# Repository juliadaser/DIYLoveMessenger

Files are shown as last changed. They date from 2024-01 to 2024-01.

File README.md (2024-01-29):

# DIY Love Messenger
By Julia Daser and Pepi Ng

Demo of Love Messengers working:
<br>
<br>
demo

## About 
Our DIY Love Messengers are the perfect gift for your friends/ partners, especially long-distance ones! When the button of one love messenger is pressed, both of them will light up - no matter HOW FAR AWAY the two messengers are! All files, code and 3D models can be found in this repository.

We also documented this in a [tutorial](https://www.youtube.com/watch?v=Ot5ihNqtx74&feature=youtu.be&ab_channel=WormiCollective)!

We are using the ESP32 microcontrollers for this tutorial. We also created a previous tutorial on [How to send data between many ESP32s from anywhere in the world](https://www.youtube.com/watch?v=Xx5cEIbBvZY&ab_channel=WormiCollective).

### Materials needed for TWO Love Messengers
1. Some translucent filament for the heart. We used [this from Elegoo](https://www.elegoo.com/products/elegoo-pla-filament-1-75mm-3d-printer-filament-1kg-spool-2-2-lbs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) 
2. Some filament of your choice, for the casing.
3. [2 ESP32-WROOM-32 microcontrollers](https://www.getfpv.com/esp32-development-board-w-wifi-bluetooth.html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) ($6.99 per)
4. [2 Adafruit 16mm illuminated push buttons](https://www.adafruit.com/product/1478) ($1.95 per)
5. Some wires
6. [Some heat shrink tubes](https://www.adafruit.com/product/1649) ($4.95 per)
7. [Two RGB LEDs](https://www.adafruit.com/product/159) ($2.00 per) 
8. [2 Micro-USB wires used to power and to transmit data](https://www.bestbuy.com/site/best-buy-essentials-3-usb-a-to-micro-usb-charge-and-sync-cable-black/6456436.p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) ($4.99 per)
9. [8x M2-0.4 x 10 mm Screws](https://www.homedepot.com/p/Prime-Line-M2-0-4-x-10-mm-Grade-A2-70-Metric-Stainless-Steel-Phillips-Drive-Pan-Head-Machine-Screws-10-Pack-9130681/311229806) ($4.69 for a pack of 10)
10. [6x 220ohm Resistors](https://www.adafruit.com/product/2780) ($0.75 for pack of 25)

### Equipment needed
1. 3D printer
2. Pliers
3. Wire Stripper
4. Small Screwdriver
5. Soldering Kit
6. Solder Sucker
7. Heat Gun / Rework station

## Process
The tutorial includes 3D printing, setting up a real-time database (we used [Firebase](https://firebase.google.com/)), uploading some arduino code and assembling everything together! 

Everything is documented in our YouTube Video. Here's the wiring diagram we used: 
<br>
<br>
<br>
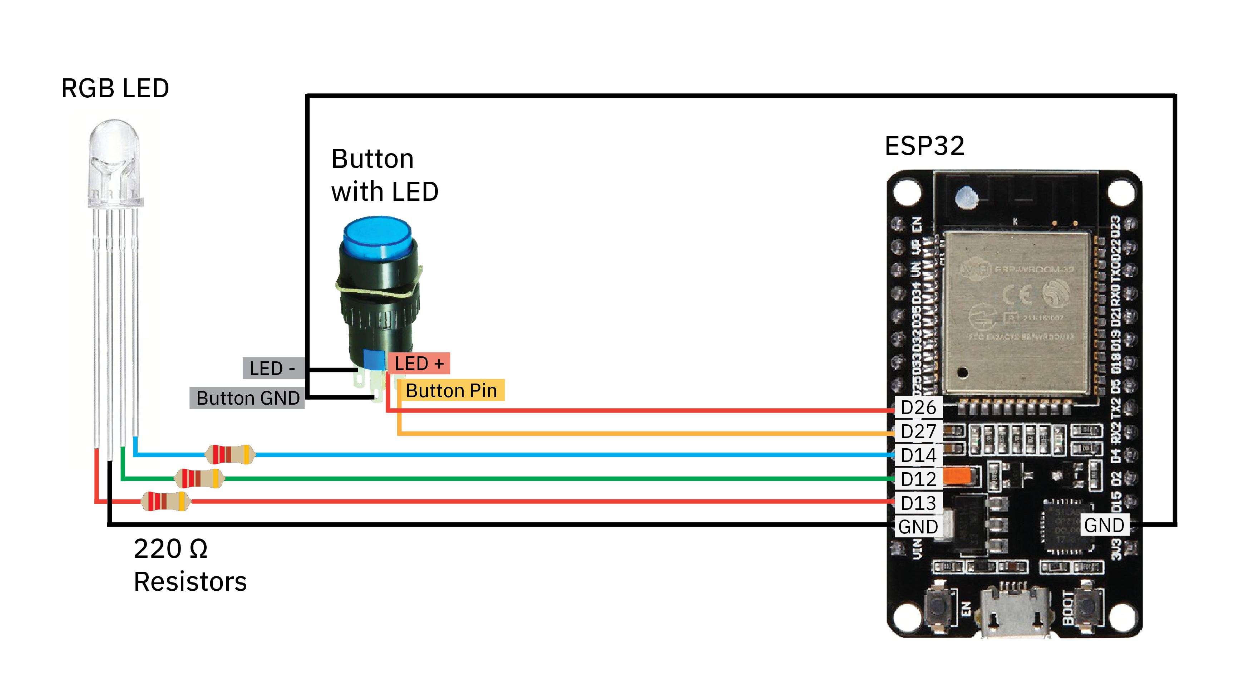
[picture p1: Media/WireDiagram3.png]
wire diagram


## Contact us
We hope you guys had tons of fun building these DIY Love Messengers as much as we did!  If you have any questions/ feedback, do reach us at yiqing.ng@gmail.com.

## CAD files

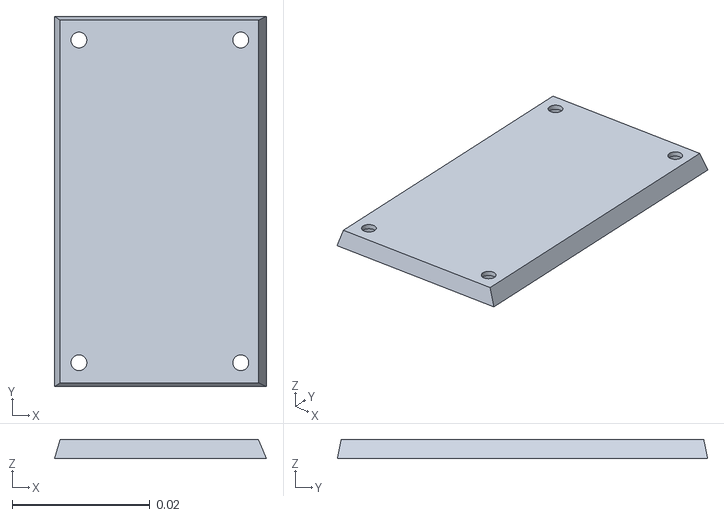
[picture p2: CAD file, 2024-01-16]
3D models/Floor.stl
0.0308 x 0.0538 x 0.00278

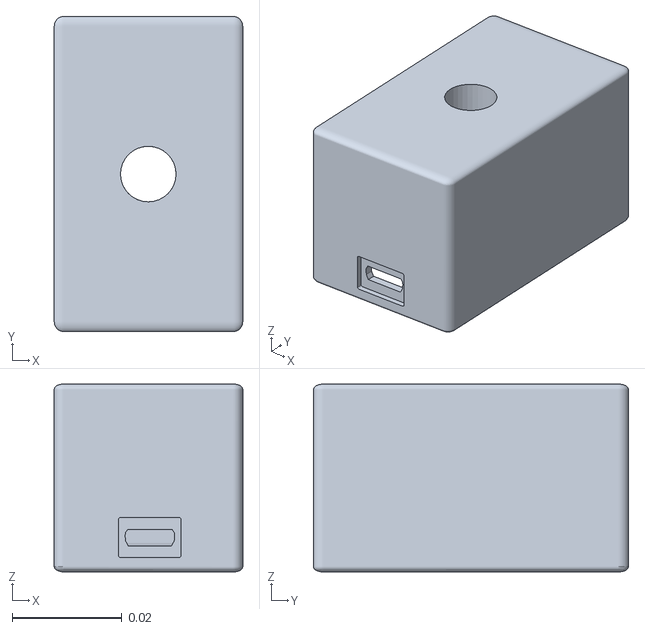
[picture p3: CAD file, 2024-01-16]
3D models/boxEncasing.stl
0.0344 x 0.0574 x 0.0342

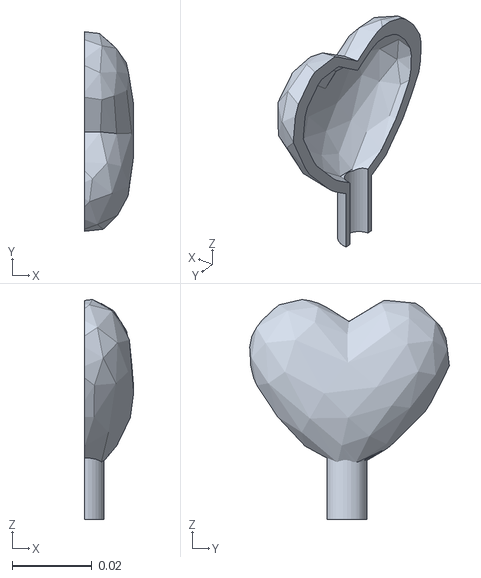
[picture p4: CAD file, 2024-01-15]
3D models/heartPart2.stl
0.0124 x 0.05 x 0.0551

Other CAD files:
3D models/heartPart1.stl

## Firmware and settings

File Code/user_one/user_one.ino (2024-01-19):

// Importing libraries
#include <Firebase_ESP_Client.h>
#include <WiFi.h>
#include "addons/TokenHelper.h"
#include "addons/RTDBHelper.h"

// Setting up your wifi connection
#define WIFI_SSID "enter ssid here"
#define WIFI_PASSWORD "enter password here"

// Setting up Firebase
#define API_KEY "enter API key here"
#define DATABASE_URL "enter api url here"

// RGB LED Pins
const int redPin = 13;
const int greenPin = 12;
const int bluePin = 14;

// RGB LED Color
int red = 0;
int green = 0;
int blue = 0;

// Color combination for RGB LED
const int colors[][3] = {
  {255, 0, 0},    // Red
  {0, 255, 0},    // Green
  {0, 0, 255},    // Blue
  {255, 150, 0},  // Yellow
  {255, 0, 255}   // Purple
};

int ledStatus = 1;

// Button Pins
#define buttonPin 27
int buttonState = 0;
int buttonStateOld = 1;
int buttonSend = 0;
int buttonLED = 26;

//Define Firebase Data object and other silly things
FirebaseData fbdo;
FirebaseAuth auth;
FirebaseConfig config;
unsigned long sendDataPrevMillis = 0;
int count = 0;
bool signupOK = false;

void connectToWiFi() {
  WiFi.begin(WIFI_SSID, WIFI_PASSWORD);
  //Serial.print("Connecting to Wi-Fi");
  while (WiFi.status() != WL_CONNECTED) {
    //Serial.print(".");
    delay(300);
  }
  //Serial.print("Connected with IP: ");
  //Serial.println(WiFi.localIP());
}

void setup() {
  // setting Baud rate
  Serial.begin(115200);

  // setting the LED pins as outputs
  pinMode(redPin, OUTPUT);
  pinMode(greenPin, OUTPUT);
  pinMode(bluePin, OUTPUT);
  pinMode(buttonLED, OUTPUT);
  // setting the button pin as an input
  pinMode(buttonPin, INPUT_PULLUP);

  // turn on the led inside the button
  analogWrite(buttonLED, 10);

  // calling connectToWiFi function
  connectToWiFi();

  // Assigning the API key, and URL
  config.api_key = API_KEY;
  config.database_url = DATABASE_URL;

  // Sign up Firebase
  if (Firebase.signUp(&config, &auth, "", "")) {
    //Serial.println("ok");
    signupOK = true;
  } else {
    //Serial.printf("%s\n", config.signer.signupError.message.c_str());
  }
  config.token_status_callback = tokenStatusCallback;
  Firebase.begin(&config, &auth);
  Firebase.reconnectWiFi(true);
}

void loop() {
  if (Firebase.ready() && signupOK && (millis() - sendDataPrevMillis > 100 || sendDataPrevMillis == 0)) {}
  sendDataPrevMillis = millis();

  // reading the button state to see if it is pressed
  int buttonState = digitalRead(buttonPin);

  // if it is pressed, choose one random color from our list
  if (buttonState == 0 and buttonStateOld == 1) {
    // Select a random color from the list
    int randomColorIndex = random(5);
    red = colors[randomColorIndex][0];
    green = colors[randomColorIndex][1];
    blue = colors[randomColorIndex][2];
    buttonSend = randomColorIndex + 1;
  }
  if (buttonState == 1) {
    buttonSend = 0;
  }

  // then light up the LED in our chosen color
  if (buttonState == 0) {
    // Turn on the LED
    analogWrite(redPin, red);
    analogWrite(greenPin, green);
    analogWrite(bluePin, blue);
  }

  // sending the buttonState to the database
  if (Firebase.RTDB.setInt(&fbdo, "/user_one", buttonSend)) {
    //Serial.println("");
    Serial.println(buttonSend);
    //Serial.println("--- successfully saved to: " + fbdo.dataPath());
    //Serial.println("(" + fbdo.dataType() + ")");
  } else {
    //Serial.println("Data upload failed");
  }

  // downloading the other person's data
  if (Firebase.RTDB.getInt(&fbdo, "/user_two")) {
    if (fbdo.dataType() == "int") {
      ledStatus = fbdo.intData();
      if (ledStatus != 0) {
        // light up our LED in the same color as the other person
        red = colors[ledStatus - 1][0];
        green = colors[ledStatus - 1][1];
        blue = colors[ledStatus - 1][2];
        analogWrite(redPin, red);
        analogWrite(greenPin, green);
        analogWrite(bluePin, blue);
      }
      if (ledStatus == 0) {
        analogWrite(redPin, 0);
        analogWrite(greenPin, 0);
        analogWrite(bluePin, 0);
      }
      //Serial.println("Successful READ from" + fbdo.dataPath() + ": " + ledStatus + "!");
    }
  } else {
    //Serial.println("Data download failed");
  }

  buttonStateOld = buttonState;
}
